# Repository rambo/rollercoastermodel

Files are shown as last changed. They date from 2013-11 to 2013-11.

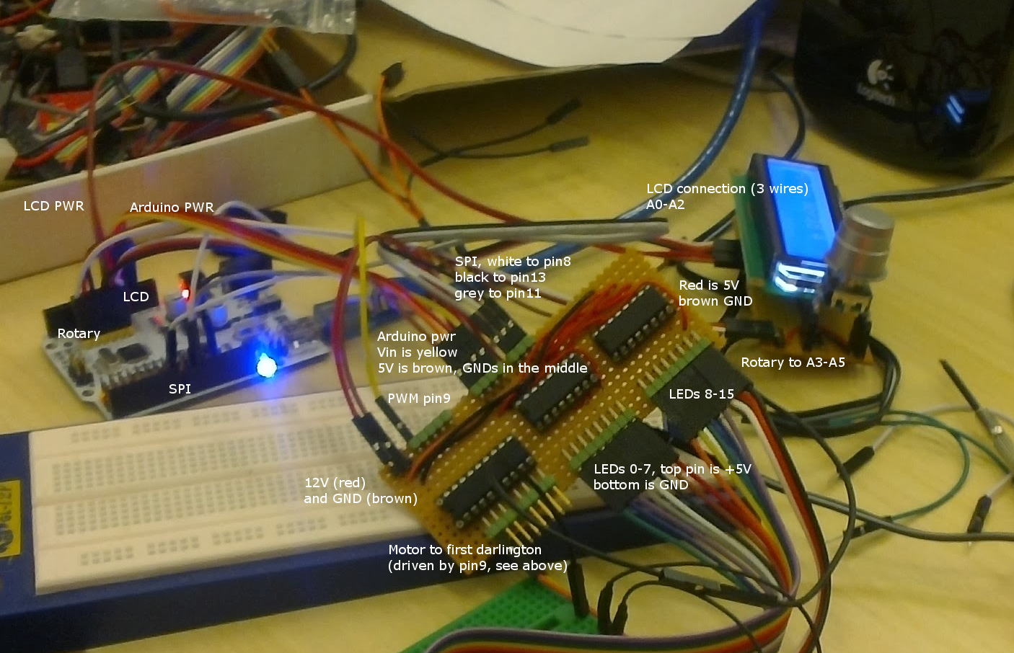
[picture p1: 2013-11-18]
rollerctrl_wiring.png

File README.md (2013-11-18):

rollercoastermodel
==================

Schematics and Arduino code related to a model rollercoaster

This was done to help Stadi Mallarit to get some new tools by building the model
to company X (I'll check later if they want their name released).

I ran out of time so some features (like adjusting each LED channel via the menu)
are not implemented at all, and the state machine for the menu in general is a bit
of a mess. It does work though.

The reason for some "weirdness" in the schematics of the IO boards is that those
were built on veroboard (in retrospect it would have been faster to make proper boards
even with all the drilling involved).

If I end up doing this menu thing better in some other project I'll come back here
and add a link, meanwhile: Be brave even if it looks like a horrible mess, there is some
decent stuff hidden in there.

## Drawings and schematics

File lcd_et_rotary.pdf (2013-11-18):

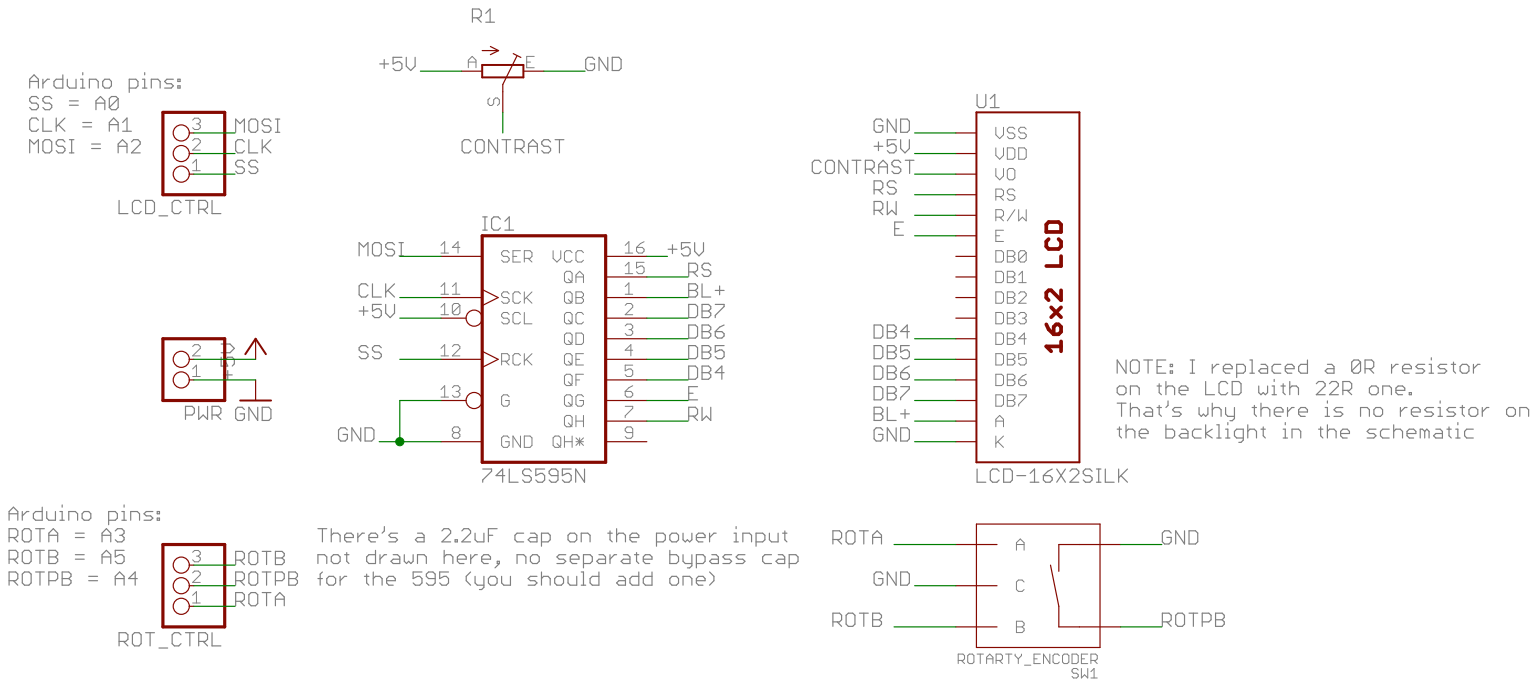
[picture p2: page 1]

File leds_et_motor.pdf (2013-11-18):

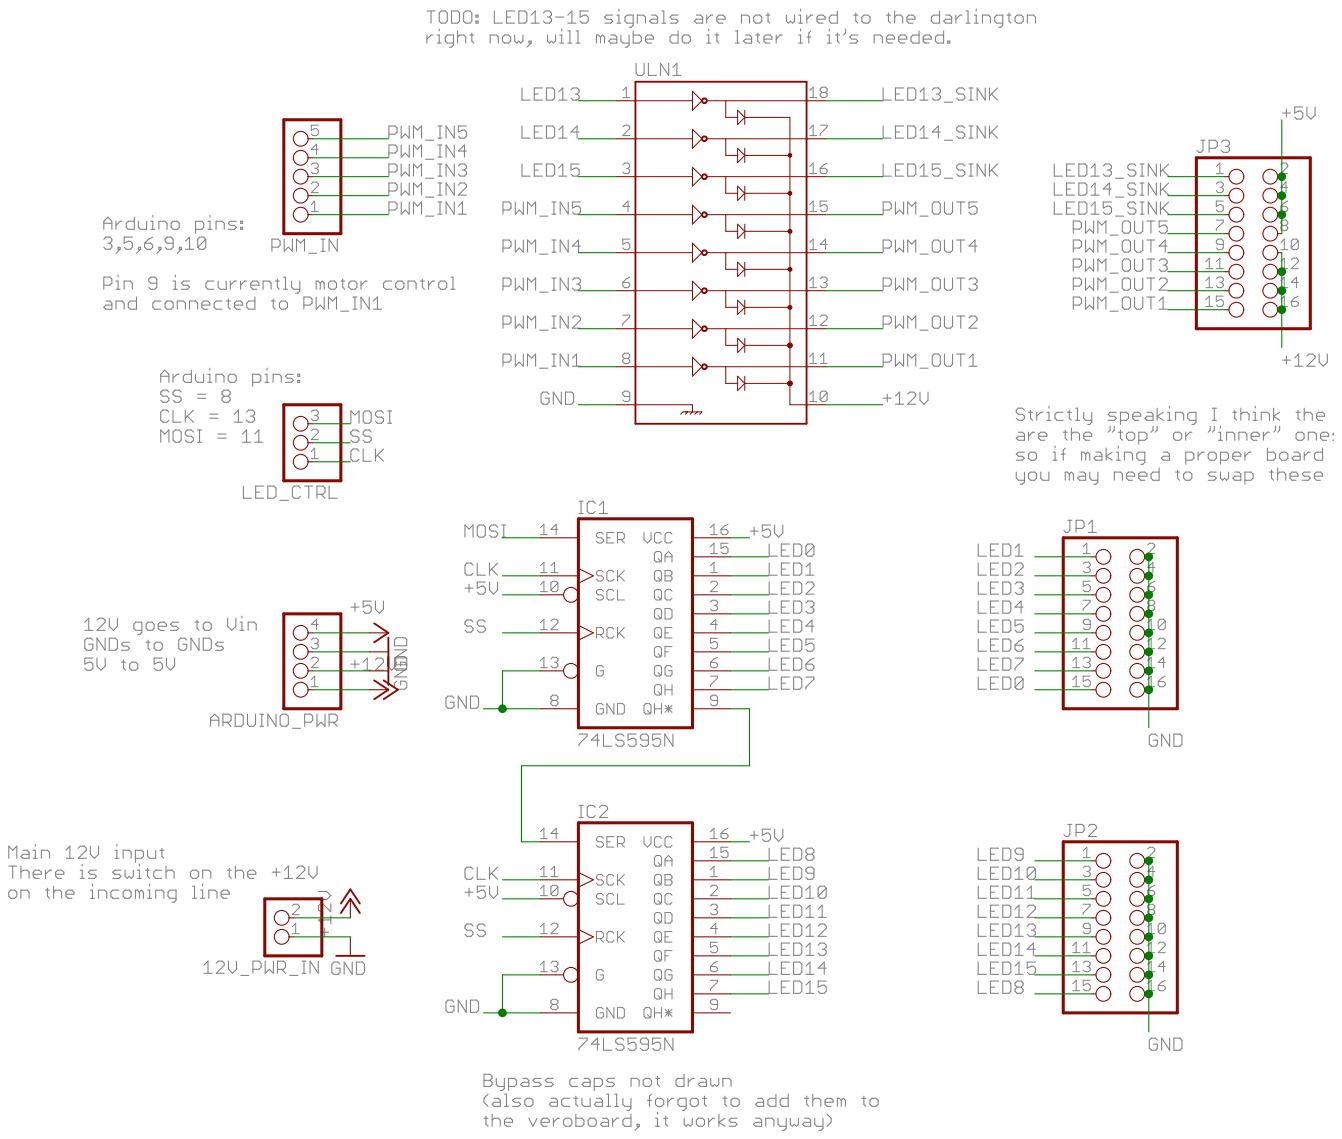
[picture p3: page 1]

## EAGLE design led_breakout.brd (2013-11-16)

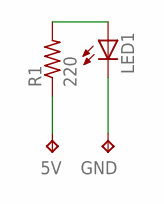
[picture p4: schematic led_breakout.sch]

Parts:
5V: TPTP13R; TP13R
GND: TPTP13SQ; TP13SQ
LED1: LEDSML0603; SML0603
R1: 220; R0603

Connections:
5V: 5V.TP, R1.1
GND: GND.TP, LED1.C
LEDSUPPLY: LED1.A, R1.2

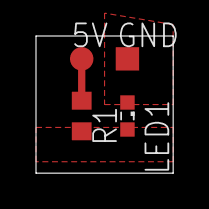
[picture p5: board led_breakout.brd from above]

Board: 2 copper layers, 7.6 x 7.6 mm, 4 parts (0 on the bottom side), 3 nets.

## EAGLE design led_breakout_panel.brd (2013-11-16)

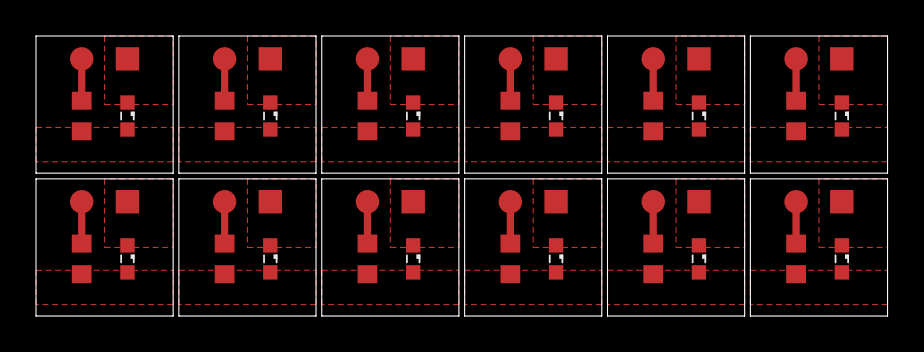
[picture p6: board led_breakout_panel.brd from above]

Board: 2 copper layers, 47.3 x 15.6 mm, 48 parts (0 on the bottom side), 36 nets.

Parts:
5V, 5V1, 5V2, 5V3, 5V4, 5V5, 5V6, 5V7, 5V8, 5V9, 5V10, 5V11: TPTP13R; TP13R
GND, GND1, GND2, GND3, GND4, GND5, GND6, GND7, GND8, GND9, GND10, GND11: TPTP13SQ; TP13SQ
LED1, LED2, LED3, LED4, LED5, LED6, LED7, LED8, LED9, LED10, LED11, LED12: SML0603
R1, R2, R3, R4, R5, R6, R7, R8, R9, R10, R11, R12: 220; R0603

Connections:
5V: 5V.TP, R1.1
5V1: 5V1.TP, R2.1
5V2: 5V2.TP, R3.1
5V3: 5V3.TP, R4.1
5V4: 5V4.TP, R5.1
5V5: 5V5.TP, R6.1
5V6: 5V6.TP, R7.1
5V7: 5V7.TP, R8.1
5V8: 5V8.TP, R9.1
5V9: 5V9.TP, R10.1
5V10: 5V10.TP, R11.1
5V11: 5V11.TP, R12.1
GND: GND.TP, LED1.C
GND1: GND1.TP, LED2.C
GND2: GND2.TP, LED3.C
GND3: GND3.TP, LED4.C
GND4: GND4.TP, LED5.C
GND5: GND5.TP, LED6.C
GND6: GND6.TP, LED7.C
GND7: GND7.TP, LED8.C
GND8: GND8.TP, LED9.C
GND9: GND9.TP, LED10.C
GND10: GND10.TP, LED11.C
GND11: GND11.TP, LED12.C
LEDSUPPLY: LED1.A, R1.2
LEDSUPPLY1: LED2.A, R2.2
LEDSUPPLY2: LED3.A, R3.2
LEDSUPPLY3: LED4.A, R4.2
LEDSUPPLY4: LED5.A, R5.2
LEDSUPPLY5: LED6.A, R6.2
LEDSUPPLY6: LED7.A, R7.2
LEDSUPPLY7: LED8.A, R8.2
LEDSUPPLY8: LED9.A, R9.2
LEDSUPPLY9: LED10.A, R10.2
LEDSUPPLY10: LED11.A, R11.2
LEDSUPPLY11: LED12.A, R12.2

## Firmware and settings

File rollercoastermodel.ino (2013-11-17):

#include <avr/pgmspace.h>
// From http://forum.arduino.cc/index.php?topic=110307.0
#define FS(x) (__FlashStringHelper*)(x)
// My improvement for array access (idea from http://forum.arduino.cc/index.php?topic=106603.0)
#define FSA(x) FS(pgm_read_word(&(x)))

// Generic helper implementation
#define ARRAY_SIZE(a)      (sizeof(a) / sizeof(a[0]))


// Note uses the *new* LiquidCrystal library https://bitbucket.org/fmalpartida/new-liquidcrystal/wiki/Home
#include <Wire.h>
#include <LCD.h>
#include <LiquidCrystal_SR3W.h>
// LiquidCrystal_SR3W lcd(DataPin, ClockPin, LatchPin, sr_enable, sr_rw, sr_rs, sr_d4, sr_d5, sr_d6, sr_d7, sr_bl, bl_pol);
LiquidCrystal_SR3W lcd(A2, A1, A0, 6, 7, 0 , 5, 4, 3, 2, 1, POSITIVE); 


// ShiftPWM library, use my fork: https://github.com/rambo/ShiftPWM
#include <SPI.h>
const uint8_t ShiftPWM_latchPin = 8;
const bool ShiftPWM_invertOutputs = false; 
const bool ShiftPWM_balanceLoad = false;
#define SHIFTPWM_USE_TIMER2
#include <ShiftPWM.h>   // include ShiftPWM.h after setting the pins!
// These are config variables ShiftPWM uses
const uint8_t maxBrightness = 255;
const uint8_t pwmFrequency = 120;
const  uint8_t numRegisters = 2;
//Usable HW-PWM pins: 3,5,6,9 & 10 (11 is taken by SPI  above)


// Config must be included *after* we know how many shift registers we have for ShiftPWM
#include <avr/eeprom.h>
#include "config.h"

// Updates shiftpwm internal state from the configration for all leds
void update_shiftpwm_all()
{
    for (uint8_t i = 0; i < sizeof(global_config.led_pwm_values); i++)
    {
        update_shiftpwm_single(i);
    }
}

// Updates shiftpwm internal state from the configration for given led
void update_shiftpwm_single(uint8_t i)
{
    int16_t tmp;
    tmp = global_config.led_pwm_values[i] + global_config.global_dimmer_adjust;
    if (tmp > 255)
    {
        tmp = 255;
    }
    if (tmp < 0)
    {
        tmp = 0;
    }
    ShiftPWM.SetOne(i, tmp);
    /*
    Serial.print(F("SetOne("));
    Serial.print(i, DEC);
    Serial.print(F(", "));
    Serial.print(tmp, DEC);
    Serial.println(F(")"));
    */
}


// http://code.google.com/p/adaencoder/ (I have older version thus still using pinchangeint and not the new oopinchangeint)
#include <PinChangeInt.h> // necessary otherwise we get undefined reference errors.
#include <AdaEncoder.h>
// Used by the encoder
int8_t clicks;
char encoder_id;
encoder *thisEncoder;


// From http://playground.arduino.cc/code/bounce
#include <Bounce.h>
Bounce bouncer = Bounce(A4, 10);
byte bouncer_value=HIGH;


// Get this library from http://bleaklow.com/files/2010/Task.tar.gz (and fix WProgram.h -> Arduino.h)
// and read http://bleaklow.com/2010/07/20/a_very_simple_arduino_task_manager.html for background and instructions
#include <Task.h>
#include <TaskScheduler.h>

#include "motortimertask.h"
MotorTimer motortimer(9);

#include "uitask.h"
UITask uitask;

void setup ( )
{
    Serial.begin(57600);
    config_eeprom_read();
    dump_config();

    // Init LCD
    lcd.begin ( 16, 2 );
    lcd.clear();
    lcd.print(F("Hello World"));

    // Init encoder (and the pushbutton)
    AdaEncoder::addEncoder('a', A3, A5);
    pinMode(A4, INPUT_PULLUP);

    // Init ShiftPWM
    pinMode(ShiftPWM_latchPin, OUTPUT);  
    SPI.setBitOrder(LSBFIRST);
    // SPI_CLOCK_DIV2 is only a tiny bit faster in sending out the last byte. 
    // SPI transfer and calculations overlap for the other bytes.
    SPI.setClockDivider(SPI_CLOCK_DIV4); 
    SPI.begin(); 
    ShiftPWM.SetAmountOfRegisters(numRegisters);
    ShiftPWM.Start(pwmFrequency,maxBrightness);

    // Set the PWMs as outputs
    /**
     * Let the tasks take care of it
    pinMode(3, OUTPUT);
    pinMode(5, OUTPUT);
    pinMode(6, OUTPUT);
    pinMode(9, OUTPUT);
    pinMode(10, OUTPUT);
     */

    // Test the LEDs    
    ShiftPWM.SetAll(maxBrightness);
    delay(1000);
    ShiftPWM.SetAll(0);
    ShiftPWM.PrintInterruptLoad();
    
    // And set the initial config state
    update_shiftpwm_all();

}

void loop ()
{
    // Initialise the task list and scheduler. (uitask must be the last one, otherwise it robs priority from everything else)
    Task *tasks[] = { &motortimer, &uitask };
    TaskScheduler sched(tasks, NUM_TASKS(tasks));
    
    // Run the scheduler - never returns.
    sched.run();
}

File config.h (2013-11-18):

#ifndef CONFIG_H
#define CONFIG_H
#include <Arduino.h>

// Use the AVR block functions directly (looping over arrays using the EEPROM Arduino library writing a byte at a time is just stupid), see also http://arduino.cc/playground/Code/EEPROMWriteAnything
#include <avr/eeprom.h>
typedef struct {
    uint16_t motor_stop_wait;
    uint16_t motor_run_wait;
    int16_t  motor_speed; // Need to catch over/underflow anyway
    uint16_t ui_idle_timeout;
    int16_t  global_dimmer_adjust; // We need we need -255 to 255 inclusive and catch going beyond those without overflows
    uint8_t  led_pwm_values[(numRegisters*8)];
    
    uint16_t magic_number;
} CoasterConfig;
CoasterConfig global_config;

void config_defaults()
{
    global_config.magic_number    = 0xdead;
    global_config.ui_idle_timeout = 30000;
    global_config.motor_stop_wait = 5000;
    global_config.motor_run_wait  = 2000;
    global_config.motor_speed     = 180; // 71% which should be close to the ~8.6V the original 555-box did.

    global_config.global_dimmer_adjust = -200;
    // I'm not 100% that is the correct way to point to a struct member but it does compile...
    memset(global_config.led_pwm_values, 255, sizeof(global_config.led_pwm_values));
}

void dump_config()
{
    Serial.println(F("global_config:"));
    Serial.print(F("  magic_number = 0x")); Serial.println(global_config.magic_number, HEX);
    Serial.print(F("  ui_idle_timeout = ")); Serial.println(global_config.ui_idle_timeout, DEC);
    Serial.print(F("  motor_stop_wait = ")); Serial.println(global_config.motor_stop_wait, DEC);
    Serial.print(F("  motor_run_wait = ")); Serial.println(global_config.motor_run_wait, DEC);
    Serial.print(F("  motor_speed = ")); Serial.println(global_config.motor_speed, DEC);
    Serial.print(F("  global_dimmer_adjust = ")); Serial.println(global_config.global_dimmer_adjust, DEC);
    for (uint8_t i = 0; i < sizeof(global_config.led_pwm_values); i++)
    {
        Serial.print(F("  led_pwm_values["));
        Serial.print(i, DEC);
        Serial.print(F("] = "));
        Serial.println(global_config.led_pwm_values[i], DEC);
    }
}

void config_eeprom_read()
{
    eeprom_read_block((void*)&global_config, (void*)0, sizeof(global_config));
    if (global_config.magic_number != 0xdead)
    {
        // Insane value, restore defaults
        Serial.println(F("EEPROM config magic number was insane, loading defaults"));
        config_defaults();
    }
}

void config_eeprom_write()
{
    cli();
    eeprom_write_block((const void*)&global_config, (void*)0, sizeof(global_config));
    sei();
}


#endif

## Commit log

2013-11-16 simple breakout
    [led_breakout.brd, led_breakout.sch]
2013-11-16 tighter package
    [led_breakout.brd]
2013-11-16 tighter panel
    [led_breakout_panel.brd]
2013-11-16 wtf, there is still some fading happening though all of the LEDs should be full-on
2013-11-16 the library works, I had forgotten to connect reset to vcc so the register was resetting at random
    [rollercoastermodel.ino]
2013-11-17 schematic for reference, I will build this on veroboard
    [lcd_et_rotary.sch]
2013-11-17 added a note about current limiting on the backlight
    [lcd_et_rotary.sch]
2013-11-17 the way it was actually built on veroboard
    [lcd_et_rotary.sch]
2013-11-17 this should be the correct pinmap bu I get nothing (not even the backlight...)
    [rollercoastermodel.ino]
2013-11-17 keep schematic and sketch consistent
    [lcd_et_rotary.sch]
2013-11-17 some more pins swapped
    [lcd_et_rotary.sch]
2013-11-17 add support for the rotary encoder
2013-11-17 free a HW-PWM pin
2013-11-17 tested motor control
2013-11-17 schematic for breaking out the shift registers for SW-PWM of leds and HW-PWM for motor
    [leds_et_motor.sch]
2013-11-17 added the darlington and pin-headers for outputs
    [leds_et_motor.sch]
2013-11-17 bring 12V in trhough this board, use 4 wires to pass the 12V to the arduino and 5V back
    [leds_et_motor.sch]
2013-11-17 tested that the new board with daisy-chained 595s works
2013-11-17 these got switched around
    [leds_et_motor.sch]
2013-11-17 simple motor control state machine
2013-11-17 avoid blinding myself when testing
    [config.h]
2013-11-17 fix a brainfart with the global adjust
    [config.h, uitask.h]
2013-11-17 too tired to figure out the new way to do this, thus including with the compat macro defined...
2013-11-17 this ought to be the correct way
    [rollercoastermodel.ino, uitask.h]
2013-11-17 menu rotation would work if I got correct data on screen...
    [rollercoastermodel.ino, uitask.h]
2013-11-17 am I running low on something else here ?? I get binary crap on the prints but very similar approeach works fine in a standalone sketch
2013-11-17 new macro to solve the array access probelm
2013-11-18 started working on the motor menu
2013-11-18 motor timer editor
2013-11-18 motor speed editor
2013-11-18 updated schematic to correspond with reality
    [leds_et_motor.sch]
2013-11-18 some notes
    [lcd_et_rotary.sch, leds_et_motor.sch]
2013-11-18 quickview versions of the schematics
2013-11-18 image (poor one but the best I had) of the wiring connections

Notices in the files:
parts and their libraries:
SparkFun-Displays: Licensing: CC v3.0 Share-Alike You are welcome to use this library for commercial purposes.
